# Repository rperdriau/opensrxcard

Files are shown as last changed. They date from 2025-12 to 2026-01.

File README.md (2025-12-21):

# opensrxcard
opensrxcard is an open source SRX card project that consists of 
- An SRX card that can be used in all compatible Roland devices (from the XV series to the Sonic Cell)
- An Arduino Due based programmer that allows to dump, program and erase SRX cards.

opensrxcard-bottom
opensrxcard+programmer


This is work in progress. Keep watching.

# Further information and documentation
Please go to the [wiki for detailed documentation](https://github.com/synthtools/opensrxcard/wiki).

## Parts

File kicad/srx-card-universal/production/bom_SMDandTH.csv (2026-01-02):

Designator | Footprint | Quantity | Value | LCSC Part #
C1, C3, C7, C8 | 0805 | 4 | 100nF | C49678
C9, C10 | CP_EIA-3528-21_Kemet-B_Pad1.50x2.35mm_HandSolder | 2 | Tantalum J106 10uF | C123255
C2, C4 | 0805 | 2 | 10nF | C1710
IC1, IC2 | TSOP-I-56_18.4x14mm_P0.5mm | 2 | MT28EW128ABA | C598856
R1 | 0805 | 1 | 100k | C149504
R2, R3, R4, R5 | 0805 | 4 | 10k | C17414
J1 | TX24-80R-6ST-H1E | 1 | TX24-80R-6ST-H1E | C5357085
J2 | PinHeader_2x02_P2.54mm_Vertical | 1 | PinHeader_2x02_P2.54mm_Vertical | C49569814

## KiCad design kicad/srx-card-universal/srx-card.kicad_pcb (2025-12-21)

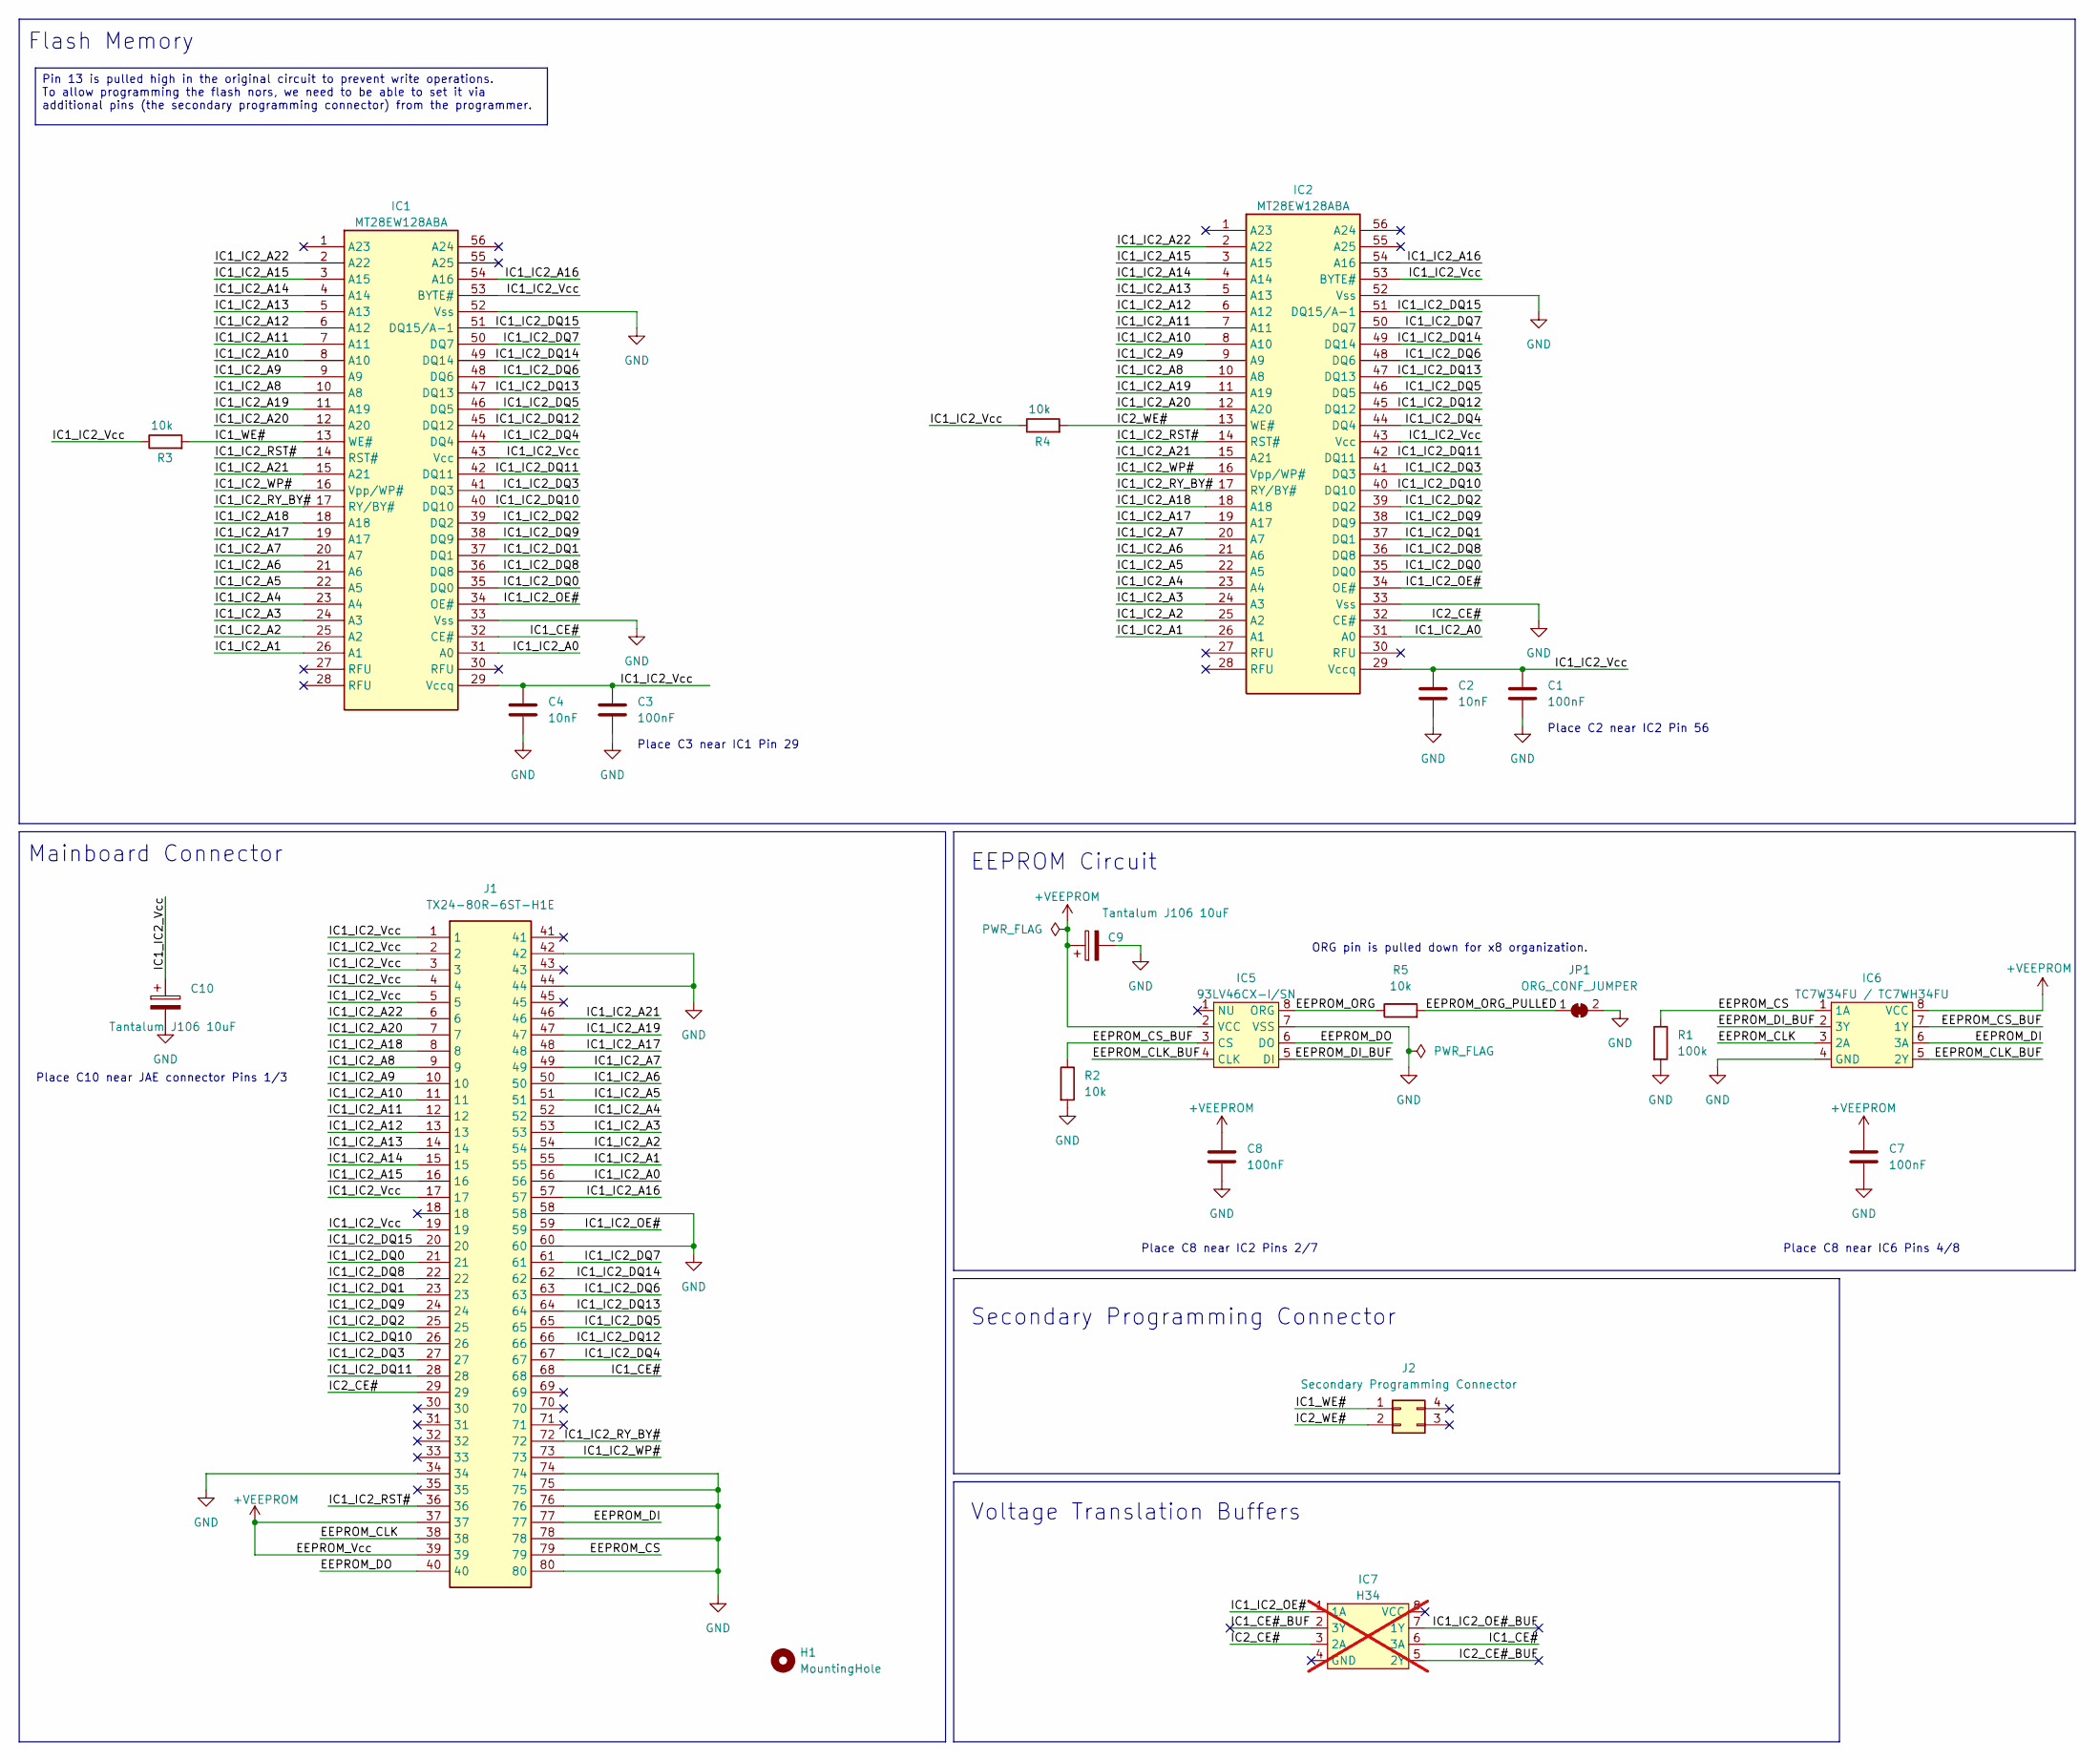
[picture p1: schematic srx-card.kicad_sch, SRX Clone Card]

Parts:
C1, C3, C7, C8: 100nF; C_0805_2012Metric_Pad1.18x1.45mm_HandSolder; LCSC C710699
C2, C4: 10nF; C_0805_2012Metric_Pad1.18x1.45mm_HandSolder; LCSC C161252
C9, C10: Tantalum J106 10uF; CP_EIA-3528-21_Kemet-B_Pad1.50x2.35mm_HandSolder; LCSC C110050
H1: MountingHole; MountingHole_5mm
IC1, IC2: MT28EW128ABA; TSOP-I-56_18.4x14mm_P0.5mm; LCSC C598856
IC5: 93LV46CX-I/SN; SOIC-8_3.9x4.9mm_P1.27mm
IC6: TC7W34FU / TC7WH34FU; SSOP-8_2.95x2.8mm_P0.65mm; LCSC C2676253
IC7: H34; SSOP-8_2.95x2.8mm_P0.65mm; not fitted
J1: TX24-80R-6ST-H1E; JAE_TX24-80R-6ST-H1E; Mouser Part Number 656-TX24-80R-6ST-H1E
J2: Secondary Programming Connector; PinHeader_2x02_P2.54mm_Vertical
JP1: ORG_CONF_JUMPER; SolderJumper-2_P1.3mm_Bridged_Pad1.0x1.5mm
R1: 100k; R_0805_2012Metric_Pad1.20x1.40mm_HandSolder; LCSC C122537
R2, R3, R4, R5: 10k; R_0805_2012Metric_Pad1.20x1.40mm_HandSolder; LCSC C441955

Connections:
+VEEPROM: C7.1, C8.1, C9.1, IC5.2 (VCC), IC6.8 (VCC), J1.37, J1.39
/EEPROM_CLK: IC6.3 (2A), J1.38
/EEPROM_CLK_BUF: IC5.4 (CLK), IC6.5 (2Y)
/EEPROM_CS: IC6.1 (1A), J1.79, R1.1
/EEPROM_CS_BUF: IC5.3 (CS), IC6.7 (1Y), R2.1
/EEPROM_DI: IC6.6 (3A), J1.77
/EEPROM_DI_BUF: IC5.5 (DI), IC6.2 (3Y)
/EEPROM_DO: IC5.6 (DO), J1.40
/EEPROM_ORG: IC5.8 (ORG), R5.1
/EEPROM_ORG_PULLED: JP1.1 (A), R5.2
/IC1_CE#: IC1.32 (CE#), IC7.6 (3A), J1.68
/IC1_IC2_A0: IC1.31 (A0), IC2.31 (A0), J1.56
/IC1_IC2_A1: IC1.26 (A1), IC2.26 (A1), J1.55
/IC1_IC2_A2: IC1.25 (A2), IC2.25 (A2), J1.54
/IC1_IC2_A3: IC1.24 (A3), IC2.24 (A3), J1.53
/IC1_IC2_A4: IC1.23 (A4), IC2.23 (A4), J1.52
/IC1_IC2_A5: IC1.22 (A5), IC2.22 (A5), J1.51
/IC1_IC2_A6: IC1.21 (A6), IC2.21 (A6), J1.50
/IC1_IC2_A7: IC1.20 (A7), IC2.20 (A7), J1.49
/IC1_IC2_A8: IC1.10 (A8), IC2.10 (A8), J1.9
/IC1_IC2_A9: IC1.9 (A9), IC2.9 (A9), J1.10
/IC1_IC2_A10: IC1.8 (A10), IC2.8 (A10), J1.11
/IC1_IC2_A11: IC1.7 (A11), IC2.7 (A11), J1.12
/IC1_IC2_A12: IC1.6 (A12), IC2.6 (A12), J1.13
/IC1_IC2_A13: IC1.5 (A13), IC2.5 (A13), J1.14
/IC1_IC2_A14: IC1.4 (A14), IC2.4 (A14), J1.15
/IC1_IC2_A15: IC1.3 (A15), IC2.3 (A15), J1.16
/IC1_IC2_A16: IC1.54 (A16), IC2.54 (A16), J1.57
/IC1_IC2_A17: IC1.19 (A17), IC2.19 (A17), J1.48
/IC1_IC2_A18: IC1.18 (A18), IC2.18 (A18), J1.8
/IC1_IC2_A19: IC1.11 (A19), IC2.11 (A19), J1.47
/IC1_IC2_A20: IC1.12 (A20), IC2.12 (A20), J1.7
/IC1_IC2_A21: IC1.15 (A21), IC2.15 (A21), J1.46
/IC1_IC2_A22: IC1.2 (A22), IC2.2 (A22), J1.6
/IC1_IC2_DQ0: IC1.35 (DQ0), IC2.35 (DQ0), J1.21
/IC1_IC2_DQ1: IC1.37 (DQ1), IC2.37 (DQ1), J1.23
/IC1_IC2_DQ2: IC1.39 (DQ2), IC2.39 (DQ2), J1.25
/IC1_IC2_DQ3: IC1.41 (DQ3), IC2.41 (DQ3), J1.27
/IC1_IC2_DQ4: IC1.44 (DQ4), IC2.44 (DQ4), J1.67
/IC1_IC2_DQ5: IC1.46 (DQ5), IC2.46 (DQ5), J1.65
/IC1_IC2_DQ6: IC1.48 (DQ6), IC2.48 (DQ6), J1.63
/IC1_IC2_DQ7: IC1.50 (DQ7), IC2.50 (DQ7), J1.61
/IC1_IC2_DQ8: IC1.36 (DQ8), IC2.36 (DQ8), J1.22
/IC1_IC2_DQ9: IC1.38 (DQ9), IC2.38 (DQ9), J1.24
/IC1_IC2_DQ10: IC1.40 (DQ10), IC2.40 (DQ10), J1.26
/IC1_IC2_DQ11: IC1.42 (DQ11), IC2.42 (DQ11), J1.28
/IC1_IC2_DQ12: IC1.45 (DQ12), IC2.45 (DQ12), J1.66
/IC1_IC2_DQ13: IC1.47 (DQ13), IC2.47 (DQ13), J1.64
/IC1_IC2_DQ14: IC1.49 (DQ14), IC2.49 (DQ14), J1.62
/IC1_IC2_DQ15: IC1.51 (DQ15/A-1), IC2.51 (DQ15/A-1), J1.20
/IC1_IC2_OE#: IC1.34 (OE#), IC2.34 (OE#), IC7.1 (1A), J1.59
/IC1_IC2_RST#: IC1.14 (RST#), IC2.14 (RST#), J1.36
/IC1_IC2_RY_BY#: IC1.17 (RY/BY#), IC2.17 (RY/BY#), J1.72
/IC1_IC2_Vcc: C1.1, C2.1, C3.1, C4.1, C10.1, IC1.29 (Vccq), IC1.43 (Vcc), IC1.53 (BYTE#), IC2.29 (Vccq), IC2.43 (Vcc), IC2.53 (BYTE#), J1.1, J1.2, J1.3, J1.4, J1.5, J1.17, J1.19, R3.1, R4.1
/IC1_IC2_WP#: IC1.16 (Vpp/WP#), IC2.16 (Vpp/WP#), J1.73
/IC1_WE#: IC1.13 (WE#), J2.1, R3.2
/IC2_CE#: IC2.32 (CE#), IC7.3 (2A), J1.29
/IC2_WE#: IC2.13 (WE#), J2.2, R4.2
GND: C1.2, C2.2, C3.2, C4.2, C7.2, C8.2, C9.2, C10.2, IC1.33 (Vss), IC1.52 (Vss), IC2.33 (Vss), IC2.52 (Vss), IC5.7 (VSS), IC6.4 (GND), J1.34, J1.42, J1.44, J1.58, J1.60, J1.74, J1.75, J1.76, J1.78, J1.80, JP1.2 (B), R1.2, R2.2

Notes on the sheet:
Flash Memory
Place C3 near IC1 Pin 29
Place C10 near JAE connector Pins 1/3
Place C2 near IC2 Pin 56
ORG pin is pulled down for x8 organization.
Voltage Translation Buffers
EEPROM Circuit
Place C8 near IC6 Pins 4/8
Place C8 near IC2 Pins 2/7
Secondary Programming Connector
Mainboard Connector
Pin 13 is pulled high in the original circuit to prevent write operations. To allow programming the flash nors, we need to be able to set it via additional pins (the secondary programming connector) from the programmer.

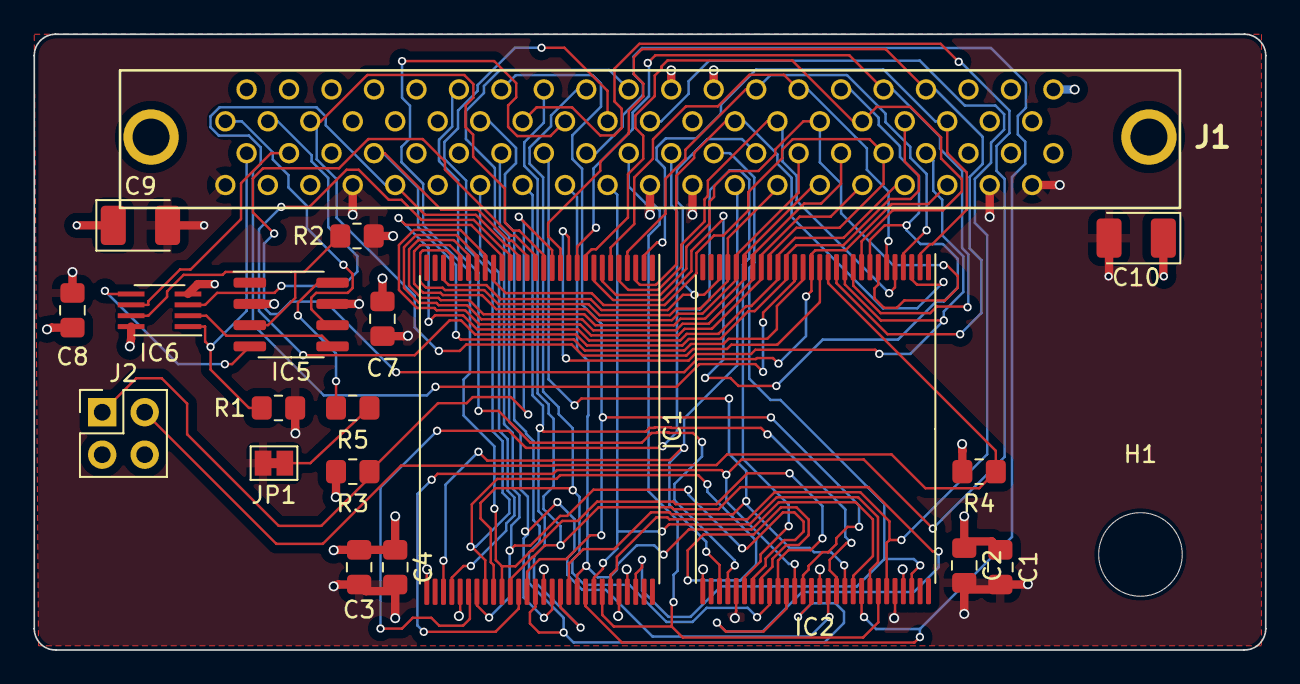
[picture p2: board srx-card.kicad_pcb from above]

Board: 4 copper layers, 73.7 x 36.8 mm, 21 parts (0 on the bottom side), 59 nets.

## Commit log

2025-12-22 Reformat BOM CSV for consistency
    [bom.csv]
2026-01-02 Upload separate files for SMD and SMD+TH versions
    Add a SMD + through-hole version for the people who would like to order assembled PCBs with connectors. Rename the SMD-only initial version. Modify the orientation of Flash EPROMs for better verifica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
    [bom_SMDandTH.csv, bom_SMDonly.csv, positions_SMDandTH.csv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]
